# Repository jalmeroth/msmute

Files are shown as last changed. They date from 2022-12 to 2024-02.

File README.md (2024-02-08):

# MS Mute

A macro pad to control Microsoft Teams (via WebSocket) while you are on-call.

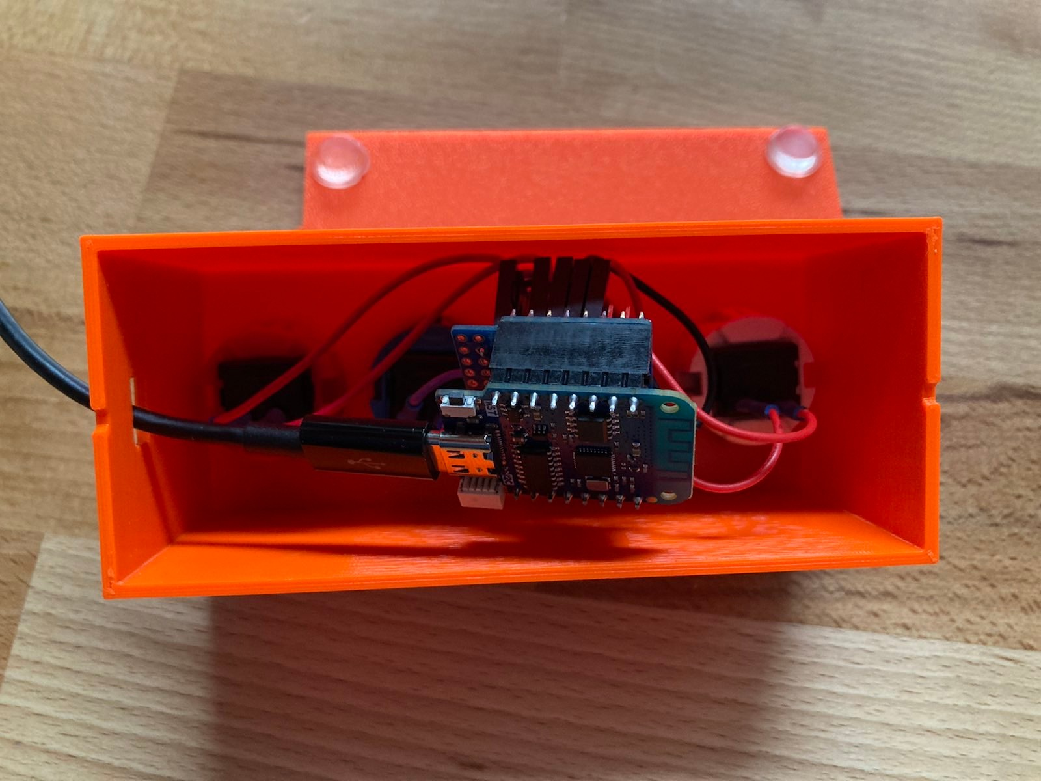
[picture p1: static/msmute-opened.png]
MS Mute - Opened

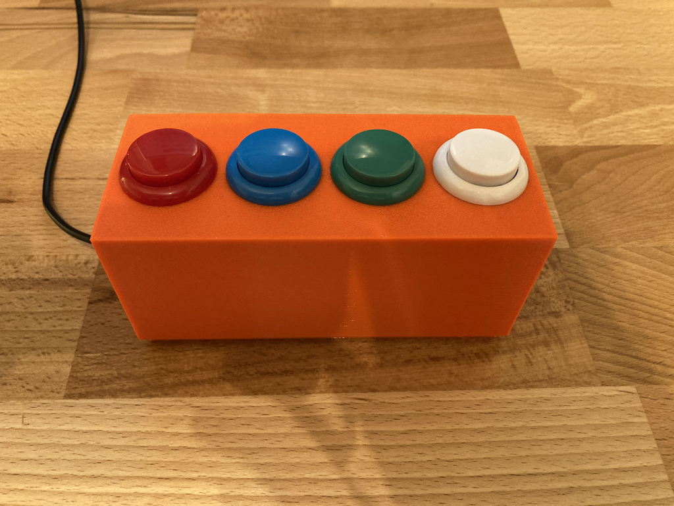
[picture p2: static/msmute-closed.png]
MS Mute - Closed


## Bill of material

- Microcontroller (e.g. [Wemos D1 mini](https://www.wemos.cc/en/latest/d1/d1_mini.html))
  - Wemos D1 mini [ProtoBoard Shield](https://www.wemos.cc/en/latest/d1_mini_shield/protoboard.html)
- 4x [Arcade Buttons](https://www.amazon.de/dp/B075DCB7LT)
- Various Jumper Wires & Resistors (4x10k/1x1k)

## Build a MS Mute device

### Assembly

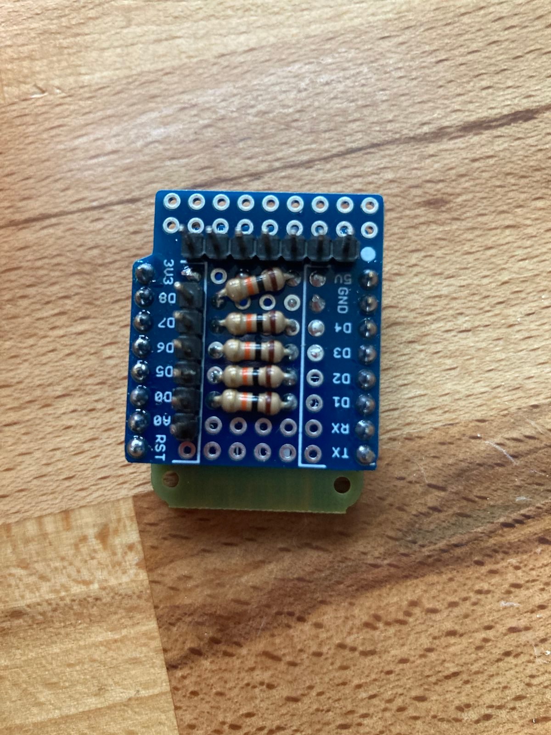
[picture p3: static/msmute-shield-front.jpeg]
"MS Mute Shield Front" MS Mute Shield Front

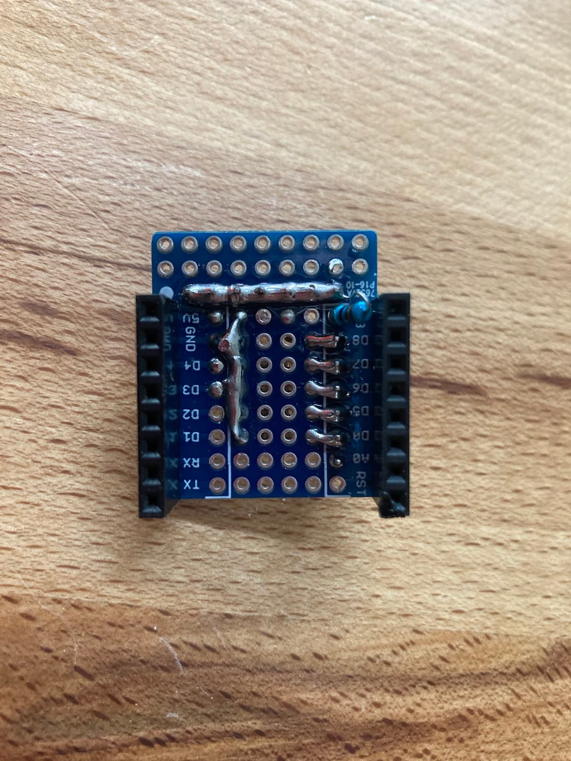
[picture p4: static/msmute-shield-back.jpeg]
"MS Mute Shield back" MS Mute Shield back


> [!WARNING]
> This is still under development

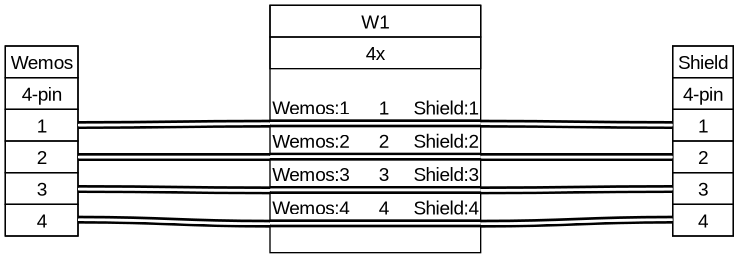
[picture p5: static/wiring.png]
"Wiring" Wiring


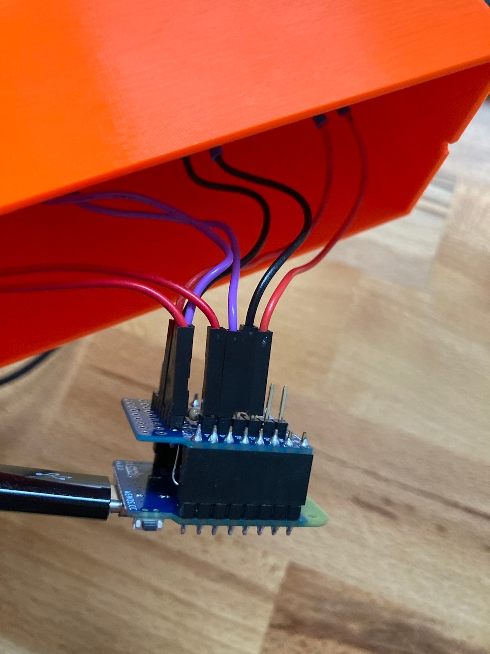
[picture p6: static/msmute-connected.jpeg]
"MS Mute connected" MS Mute connected


### Flashing MicroPython

For more information on flashing MicroPython to the microcontroller take a look here: <https://www.wemos.cc/en/latest/tutorials/d1/get_started_with_micropython_d1.html>

### Buttons

| pin | color | action | description |
| --- | ----- | --- | --- |
| 14  | white | toggle-hand  | Raise or lower hand  |
| 12  | green | toggle-mute  | Toggle mute on/off |
| 13  | blue  | toggle-video | Toggle camera on/off |
| 15  | red | leave-call | Leave the meeting |

### Copy project files

You can use `adafruit-ampy` to copy the files to your board. Checkout the tutorial here: <https://learn.adafruit.com/micropython-basics-load-files-and-run-code/overview>.

```sh
# switch working directory to `src`
cd src
# copy all files to the microcontroller
ampy --port /dev/ttyUSB1 put ./ /
```

#### Configuration

```json filename=config.json
{
  […]
  "WS_TOKEN": "49e618ec-b17e-4129-98fd-4d8c266e0041",
  "WS_URI": "ws://192.168.0.100:8123"
}
```

The value for `WS_TOKEN` is generated by **Microsoft Teams** once the third-party device pairing was successful. See [General Setup](#general-setup-macos) for more information.

`WS_URI` consists of the prefix `ws://` for a WebSocket connection, your computers IP address (e.g `192.168.0.101`) and the exposed port `8123`. See [Exposing the port externally](#exposing-the-port-externally) for more information.

## General Setup (macOS)

### Enable Third-party app API

In **Microsoft Teams** go to Settings > Privacy > Third-party app API > check **enable**.
This will start the WebSocket-Server on port `8124`.

You can validate this by running `lsof` in **Terminal.app**:

```sh
# check if Teams opened the port on localhost
lsof | grep 8124
```

The output should show a line with something like `TCP localhost:8124 (LISTEN)`.

For more information refer to [Microsofts documentation](https://support.microsoft.com/en-us/office/connect-to-third-party-devices-in-microsoft-teams-aabca9f2-47bb-407f-9f9b-81a104a883d6).

### Aquiring a refresh token

In the **Developer Console** of your browser switch to the **Network** tab and make sure can see the **Console** below:

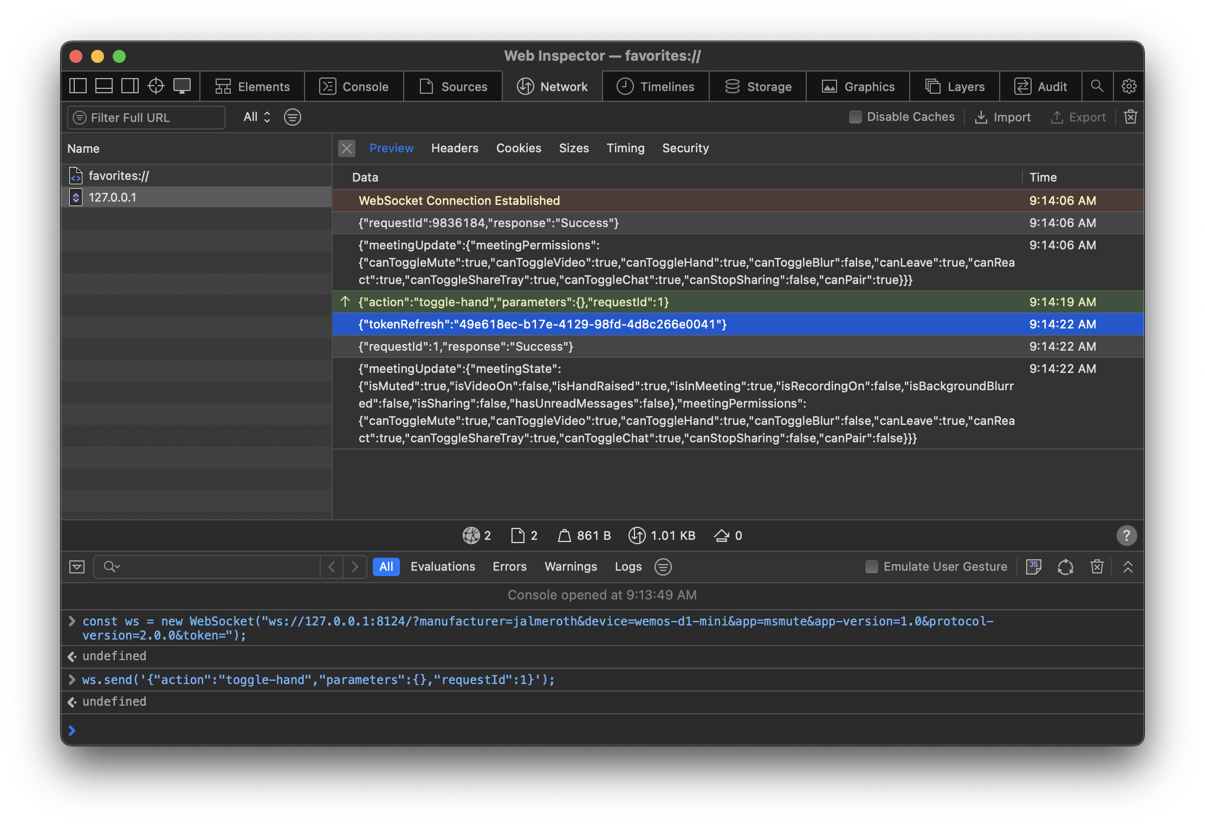
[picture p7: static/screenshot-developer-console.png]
"Screenshot from Developer Console" Screenshot from Developer Console


Lets connect to the Teams WebSocket-Server:

```js
const ws = new WebSocket(
  "ws://127.0.0.1:8124/?manufacturer=jalmeroth&device=wemos-d1-mini&app=msmute&app-version=1.0&protocol-version=2.0.0&token=",
);
```

Now join a Teams meeting and issue the following command in **Developer Console**:

```js
ws.send('{"action":"toggle-hand","parameters":{},"requestId":1}');
```

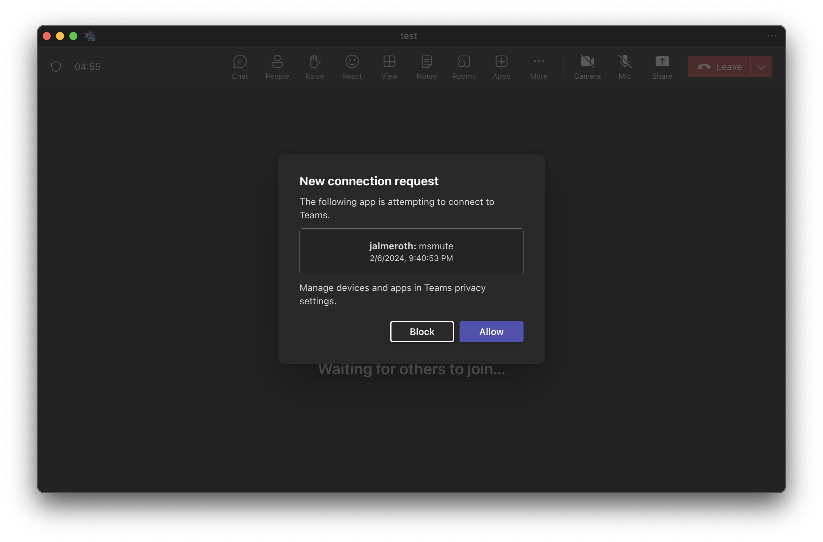
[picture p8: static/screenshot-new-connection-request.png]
"Screenshot from New connection request" Screenshot from New connection request


You will see a window to **Allow** or **Block** a new connection request.
Tapping **Allow** means the third-party device will pair and can interact with Teams; it will be added to the **Allowed apps and devices** list.

Pairing the device will issue a `tokenRefresh` as seen in the screenshot above.

The `tokenRefresh` value must be copied as `WS_TOKEN` in your `config.json`.

### Exposing the port externally

Since the WebSocket-Server port is bound to `localhost` we need to expose it externally. We can use `socat` for this:

```sh
# Install `socat` via `brew` first
brew install socat
# Export local-bound port (8124) on different port (e.g. 8123)
socat -4 TCP-Listen:8123,reuseaddr,fork TCP:localhost:8124
```

## CAD

The 3D-files for the enclosure can be found in [cad](./cad/)

## Further reading

- <https://techcommunity.microsoft.com/t5/microsoft-teams-blog/delivering-new-webinar-experiences-with-microsoft-teams/ba-p/3725145>
- <https://techcommunity.microsoft.com/t5/healthcare-and-life-sciences/update-5-using-the-native-elgato-stream-deck-integration-with/ba-p/3732044>
- <https://techcommunity.microsoft.com/t5/healthcare-and-life-sciences/elgato-stream-deck-now-working-in-the-new-teams-hls-show-me-how/ba-p/3977684>

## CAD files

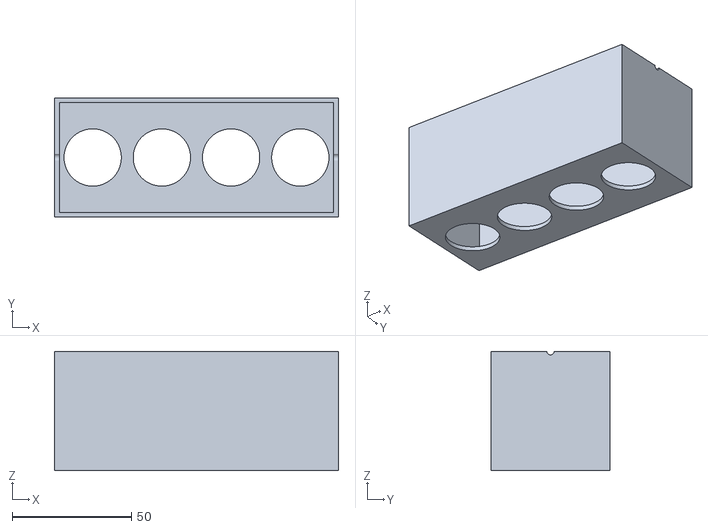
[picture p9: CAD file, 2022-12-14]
cad/top.stl
119.0 x 50.0 x 50.0

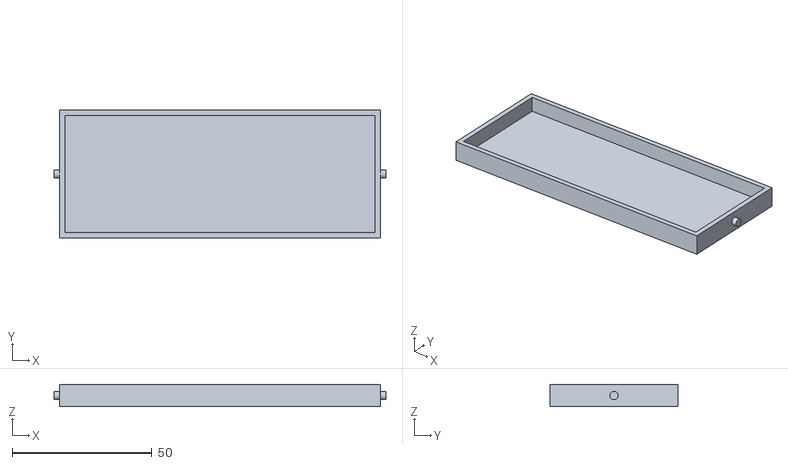
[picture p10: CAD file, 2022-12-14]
cad/bottom.stl
119.0 x 46.0 x 8.00

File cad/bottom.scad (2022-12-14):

$fn=100;
// wall
$ws=2;
// box
$by=50-2*$ws;
$bx=119-2*$ws;
$bz=10-$ws;


translate([$ws,$ws,0])
difference() {
    union() {
        cube([$bx,$by,$bz]);
        translate([-$ws,$by/2,$bz/2])
        rotate([0,90,0])
        cylinder(h=119,d=3);
    }
    translate([$ws,$ws,$ws])
    cube([$bx-2*$ws,$by-2*$ws,$bz-$ws+3]);
}

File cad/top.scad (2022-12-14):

$fn=100;
// wall
$ws=2;
// box
$by=50;
$bx=119;
$bz=50;
// knops
$kd=24;
$kr=$kd/2;
// cable
$cx=6;
$cy=10;

difference() {
    cube([$bx,$by,$bz]);
    translate([$ws,$ws,$ws])
    cube([$bx-2*$ws,$by-2*$ws,$bz-$ws]);
    translate([2*$ws,0,0])
    union() {
        for(i=[0:3]) {
            $x=$kr+(i*($kd+5));
            echo($x);
            translate([$x,$by/2,0])
            cylinder(h=$ws, d=$kd);
        }
    }
    // Power cable
    translate([$ws,($by-$cy)/2,$bz-$cx-10])
    rotate([0,-90,0])
    cube([$cx,$cy,$ws]);
    // Closing
    translate([0,$by/2,$bz])
    rotate([0,90,0])
    cylinder(h=$bx,d=3);
}

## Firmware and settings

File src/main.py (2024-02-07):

"""Provide mqtt-remote functions."""
import json
from time import sleep, ticks_ms

from config import Config
from debounce import Debounce
from machine import Pin, reset
from net import NetworkManager
from uwebsockets import client as ws_client  # https://github.com/danni/uwebsockets

CONFIG = Config()
DEVICE_NAME = getattr(CONFIG, "DEVICE_NAME", "msmute")
WS_TOKEN = getattr(CONFIG, "WS_TOKEN", "")
WS_URI = getattr(CONFIG, "WS_URI", "")


def button_callback(pin, action):
    """Provide a callback for buttons."""
    print(pin, action)
    params = {
        "app": "msmute",
        "app-version": "1.0",
        "device": "wemos-d1-mini",
        "manufacturer": "jalmeroth",
        "protocol-version": "2.0.0",
        "token": f"{WS_TOKEN}",
    }
    paramstr = "&".join([f"{k}={v}" for k, v in params.items()])
    websocket = ws_client.connect(WS_URI, f"/?{paramstr}")
    if websocket is None:
        return
    data = {
        "action": action,
        "parameters": {},
        "requestId": 1,
    }
    request = json.dumps(data)
    websocket.send(request)
    print(f"> {request}")
    response = websocket.recv()
    print(f"< {response}")
    websocket.close()


def main():
    """Provide main routine."""
    # Setup the button input pin with a pull-up resistor.
    Debounce(Pin(14, Pin.IN), button_callback, action="toggle-hand")
    Debounce(Pin(12, Pin.IN), button_callback, action="toggle-mute")
    Debounce(Pin(13, Pin.IN), button_callback, action="toggle-video")
    Debounce(Pin(15, Pin.IN), button_callback, action="leave-call")

    ssid = getattr(CONFIG, "WIFI_SSID", "")
    password = getattr(CONFIG, "WIFI_PASS", "")
    NetworkManager().do_connect(ssid, password)

    while True:
        sleep(1)


if __name__ == "__main__":
    try:
        main()
    except KeyboardInterrupt:
        print("KeyboardInterrupt")
    except OSError as err:
        print(f"Resetting: {err}")
        reset()

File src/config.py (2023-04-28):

"""Provide functions to handle config."""
import json

from const import CONFIG_FILE


class Config:
    """Represent a config object."""

    def __init__(self) -> None:
        self._data = None
        try:
            self.data = self._load()
        except OSError:
            print("Load config failed")
            self.data = {}

    def _load(self):
        """Load a config."""
        print("Loading config")
        with open(CONFIG_FILE, "rb") as config_file:
            try:
                data = json.load(config_file)
            except ValueError:
                print("JSON Load failed")
                data = {}
        return data

    def save(self, data):
        """Save a config."""
        with open(CONFIG_FILE, "w+", encoding="utf-8") as config_file:
            try:
                json.dump(data, config_file)
            except ValueError:
                print("Save config failed")
            else:
                self.data = data

    @property
    def data(self):
        """Returns data dict."""
        return self._data

    @data.setter
    def data(self, obj):
        if isinstance(obj, dict):
            self._data = obj
            for key in obj:
                setattr(self, key, obj[key])
